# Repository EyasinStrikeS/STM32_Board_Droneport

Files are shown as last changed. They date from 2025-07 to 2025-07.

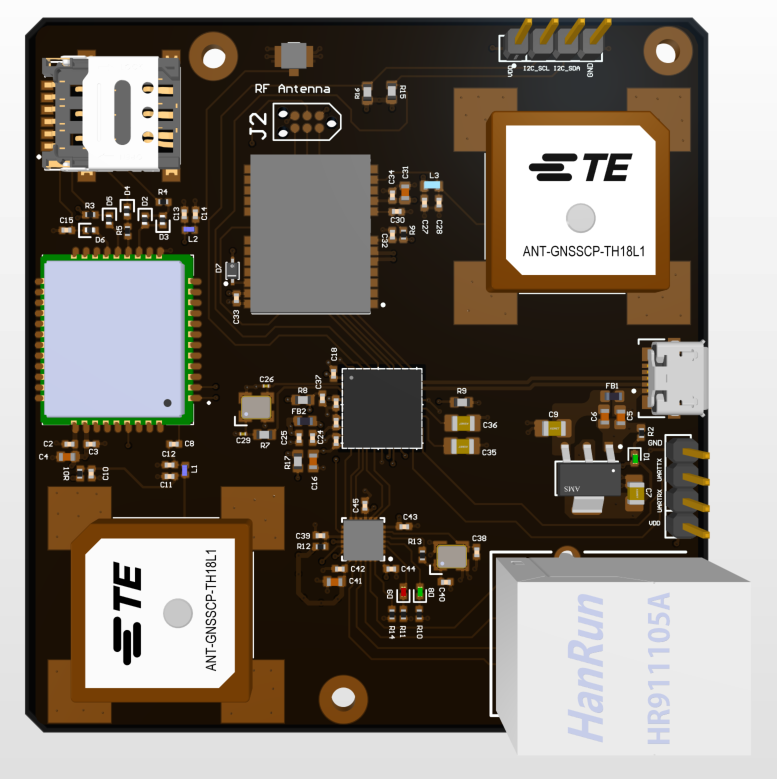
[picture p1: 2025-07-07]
Hardware/PCB/3D PCB View.png

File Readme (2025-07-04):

# Droneport STM32 Hardware Design

## Overview

This project contains the complete schematic and PCB layout for a custom embedded system designed to serve as a **Droneport Communication Controller**. The board integrates multiple interfaces for embedded control and communication:

- STM32H730VBH6 microcontroller
- Ethernet (LAN8720A + RJ45 with magnetics)
- LTE + GNSS module (SIM7080G + NEO-M8N)
- USB, UART, SPI, I2C, SWD, SIM card
- Power regulation (AMS1117-3.3)
- Antenna inputs for GNSS and LTE
- Debug and programming header

---

## Features

- **Core MCU**: STM32H730VBH6 (Cortex-M7, 550 MHz)
- **Communication**:
  - Ethernet via LAN8720A
  - LTE Cat-M/NB-IoT + GNSS via SIM7080G
  - GPS/GNSS via u-blox NEO-M8N
- **Power**: USB 5V input, regulated 3.3V for logic
- **Interfaces**: UARTs, I2C, SPI, SWD debug
- **Antenna**: U.FL for GNSS, LTE RF antenna
- **Connector**: RJ45, USB Micro-B, SIM slot

---

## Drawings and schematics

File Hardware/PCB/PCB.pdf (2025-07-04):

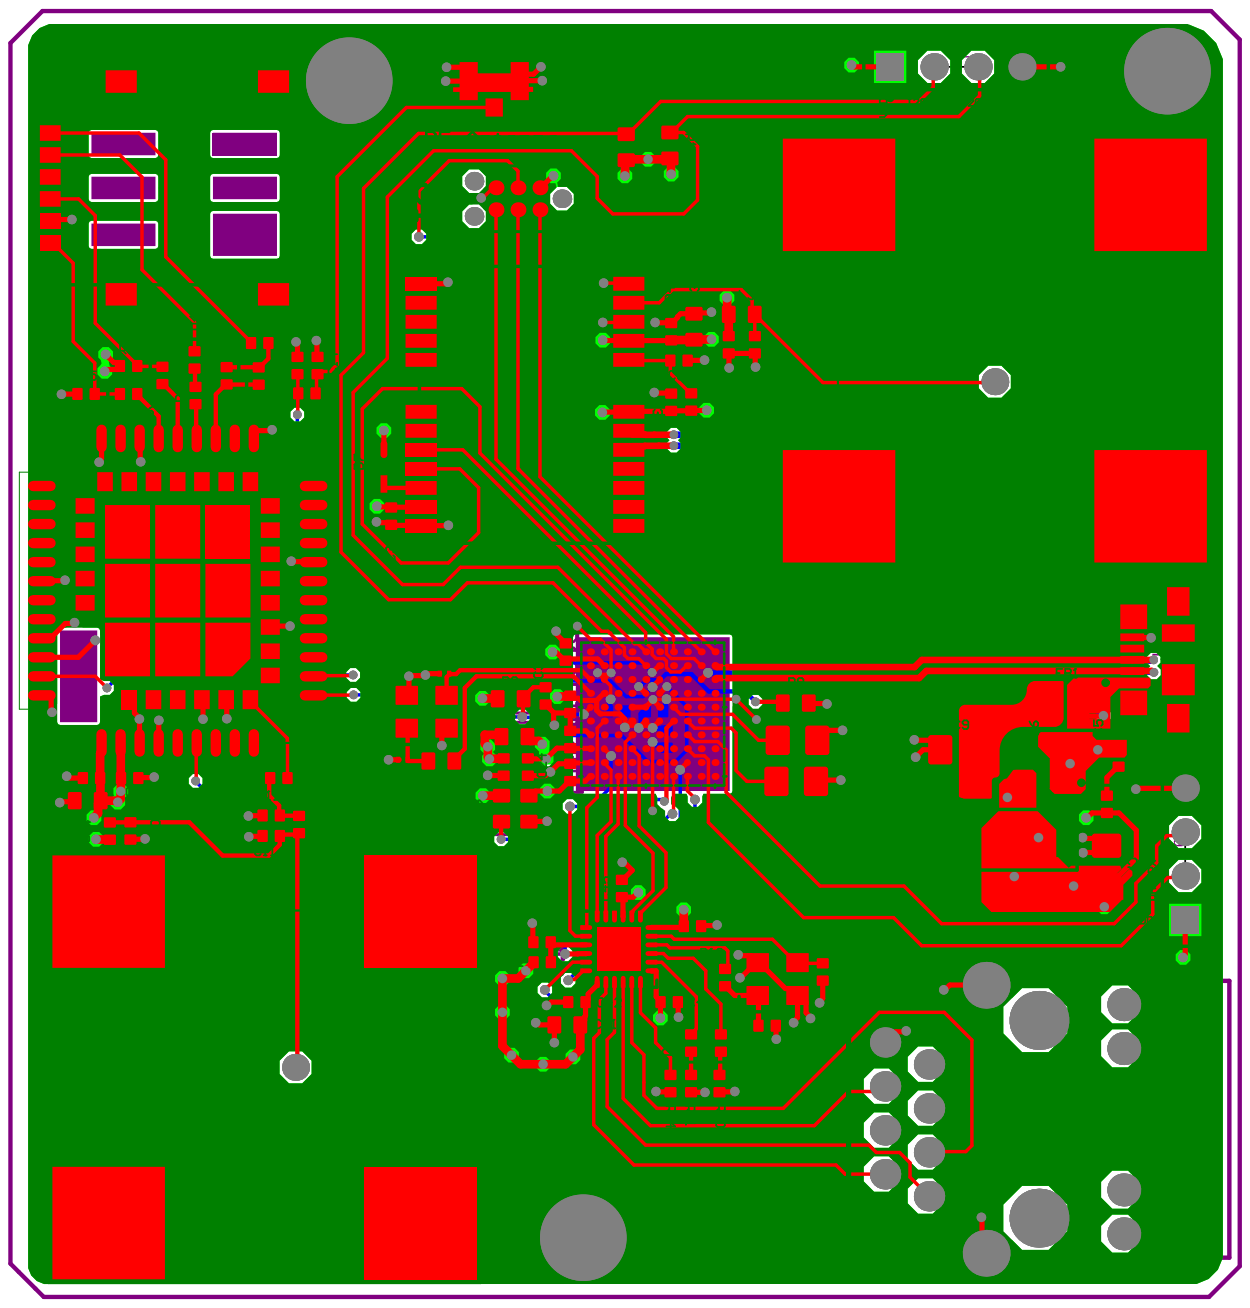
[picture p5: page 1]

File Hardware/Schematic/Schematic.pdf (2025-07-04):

PC15-OSC32_OUT B1 | VBAT B²
PC3_C F3 | VDD F⁴ VDD F⁵ | VDD³USB F⁶

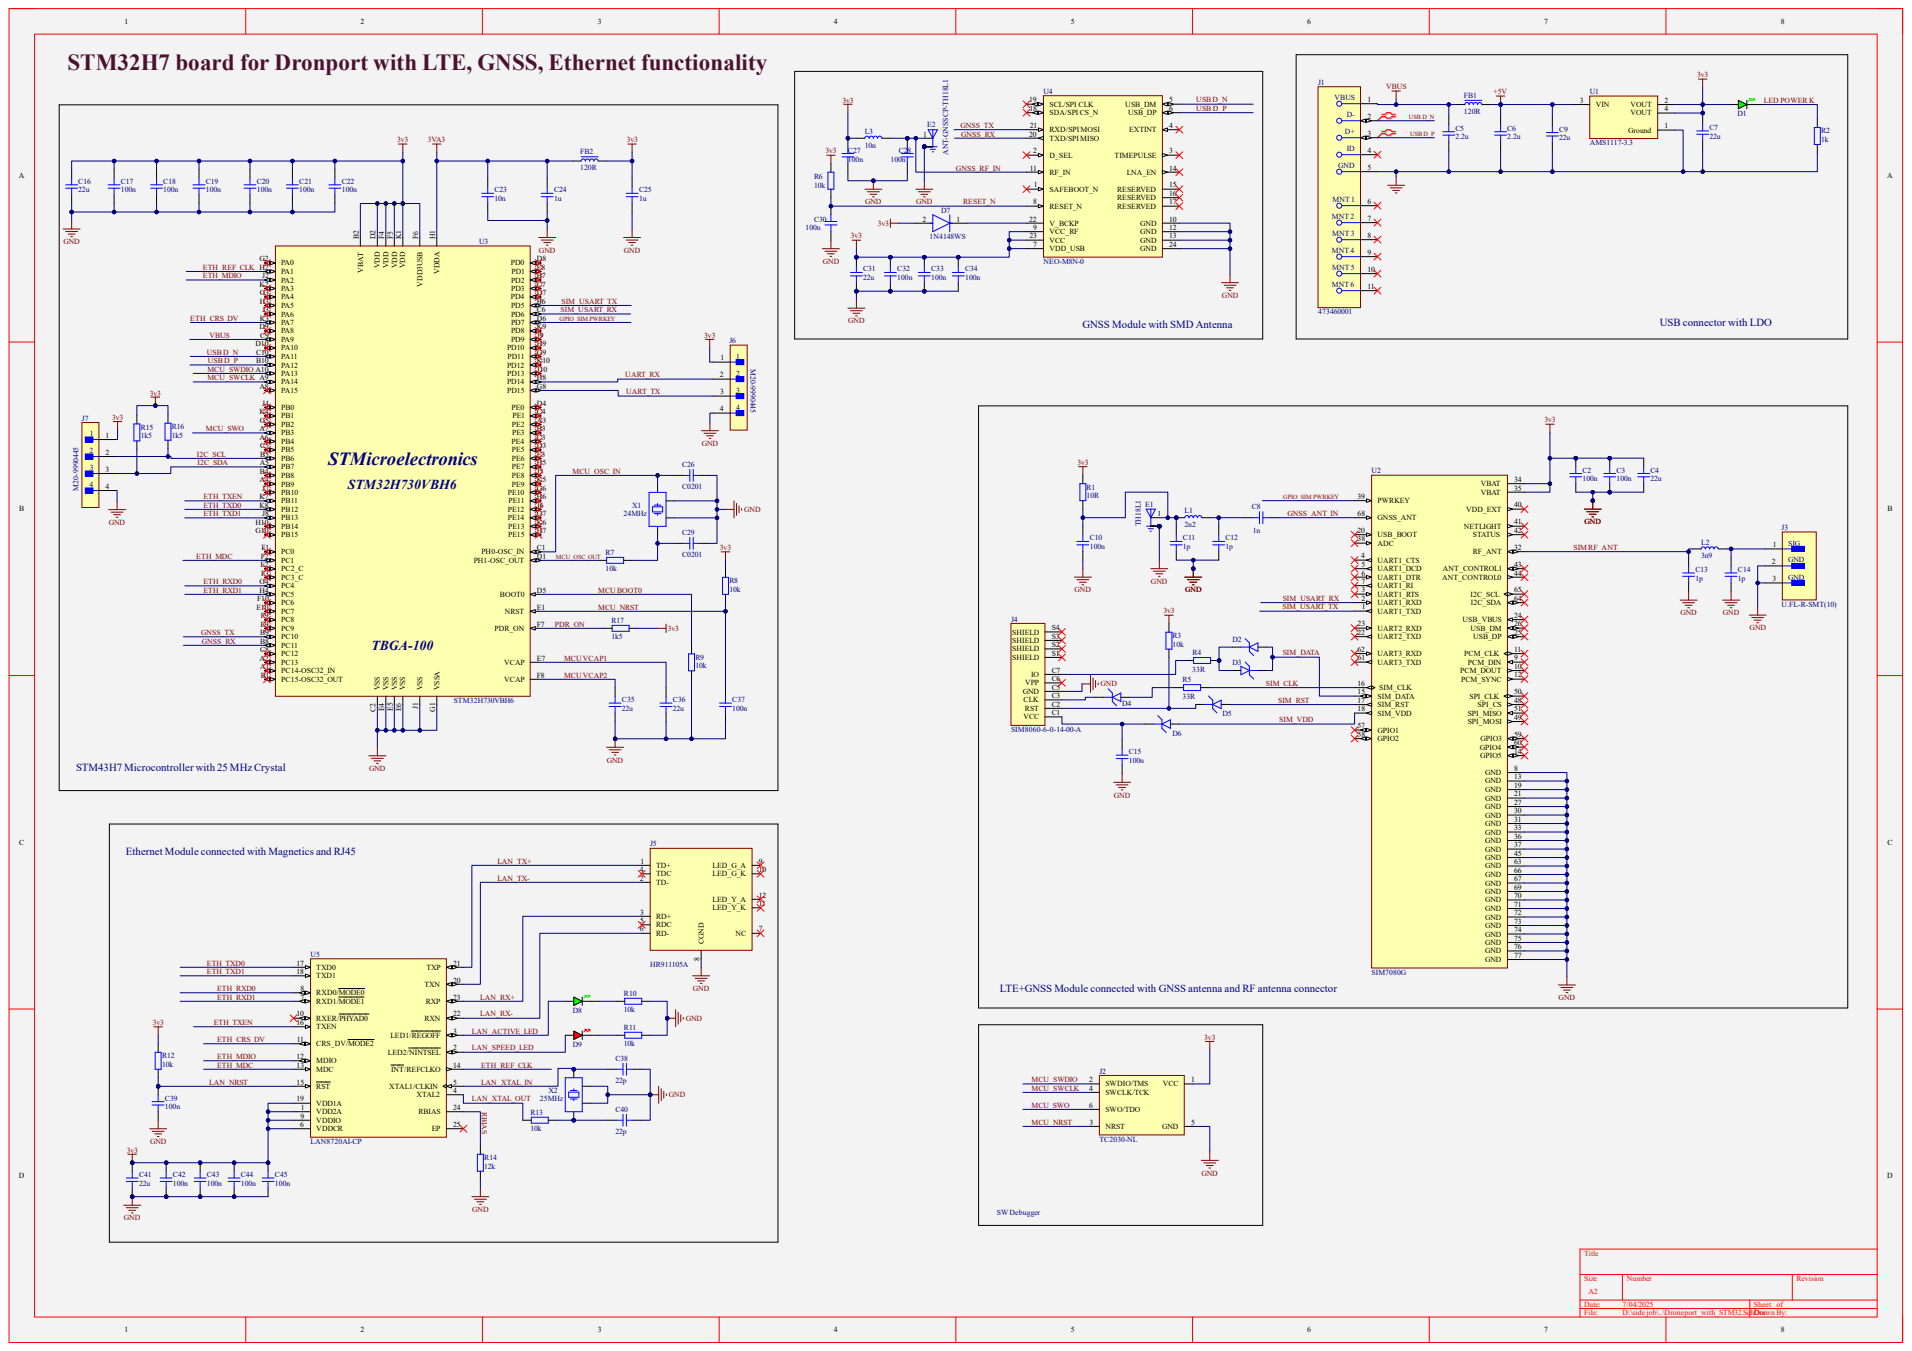
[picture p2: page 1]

STM32H7 board for Dronport with LTE, GNSS, Ethernet functionality

STM43H7 Microcontroller with 25 MHz Crystal

Ethernet Module connected with Magnetics and RJ45

LTE+GNSS Module connected with GNSS antenna and RF antenna connector

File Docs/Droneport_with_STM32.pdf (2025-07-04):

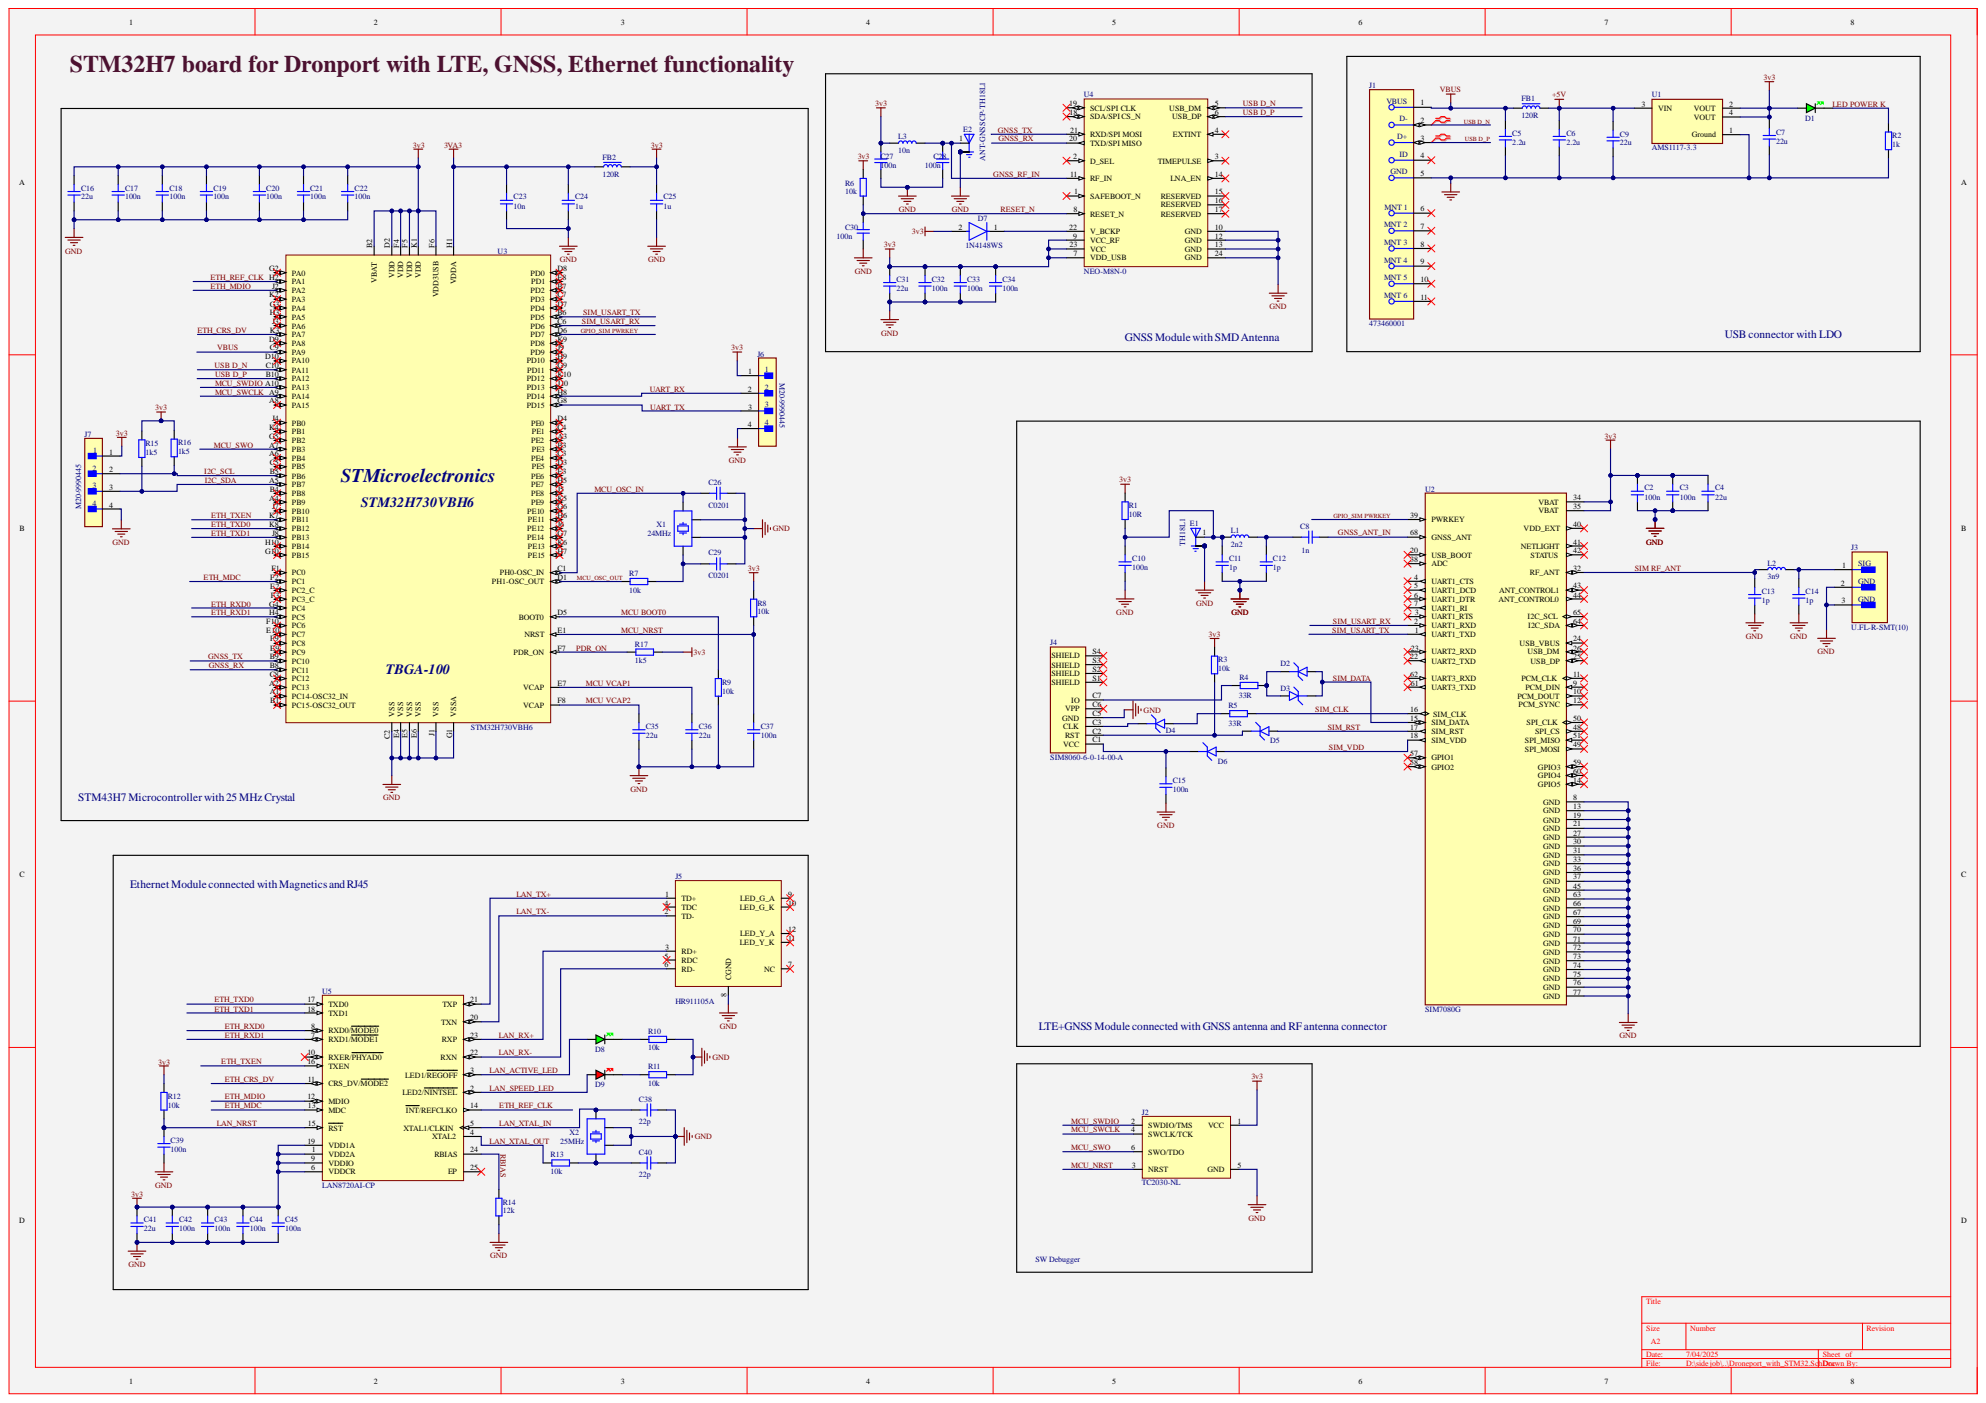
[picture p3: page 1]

STM32H7 board for Dronport with LTE, GNSS, Ethernet functionality

3 | I2C_SDA

I2C_SCL

SIM_VDD | GPIO1 57

STM43H7 Microcontroller with 25 MHz Crystal

Ethernet Module connected with Magnetics and RJ45

LTE+GNSS Module connected with GNSS antenna and RF antenna connector

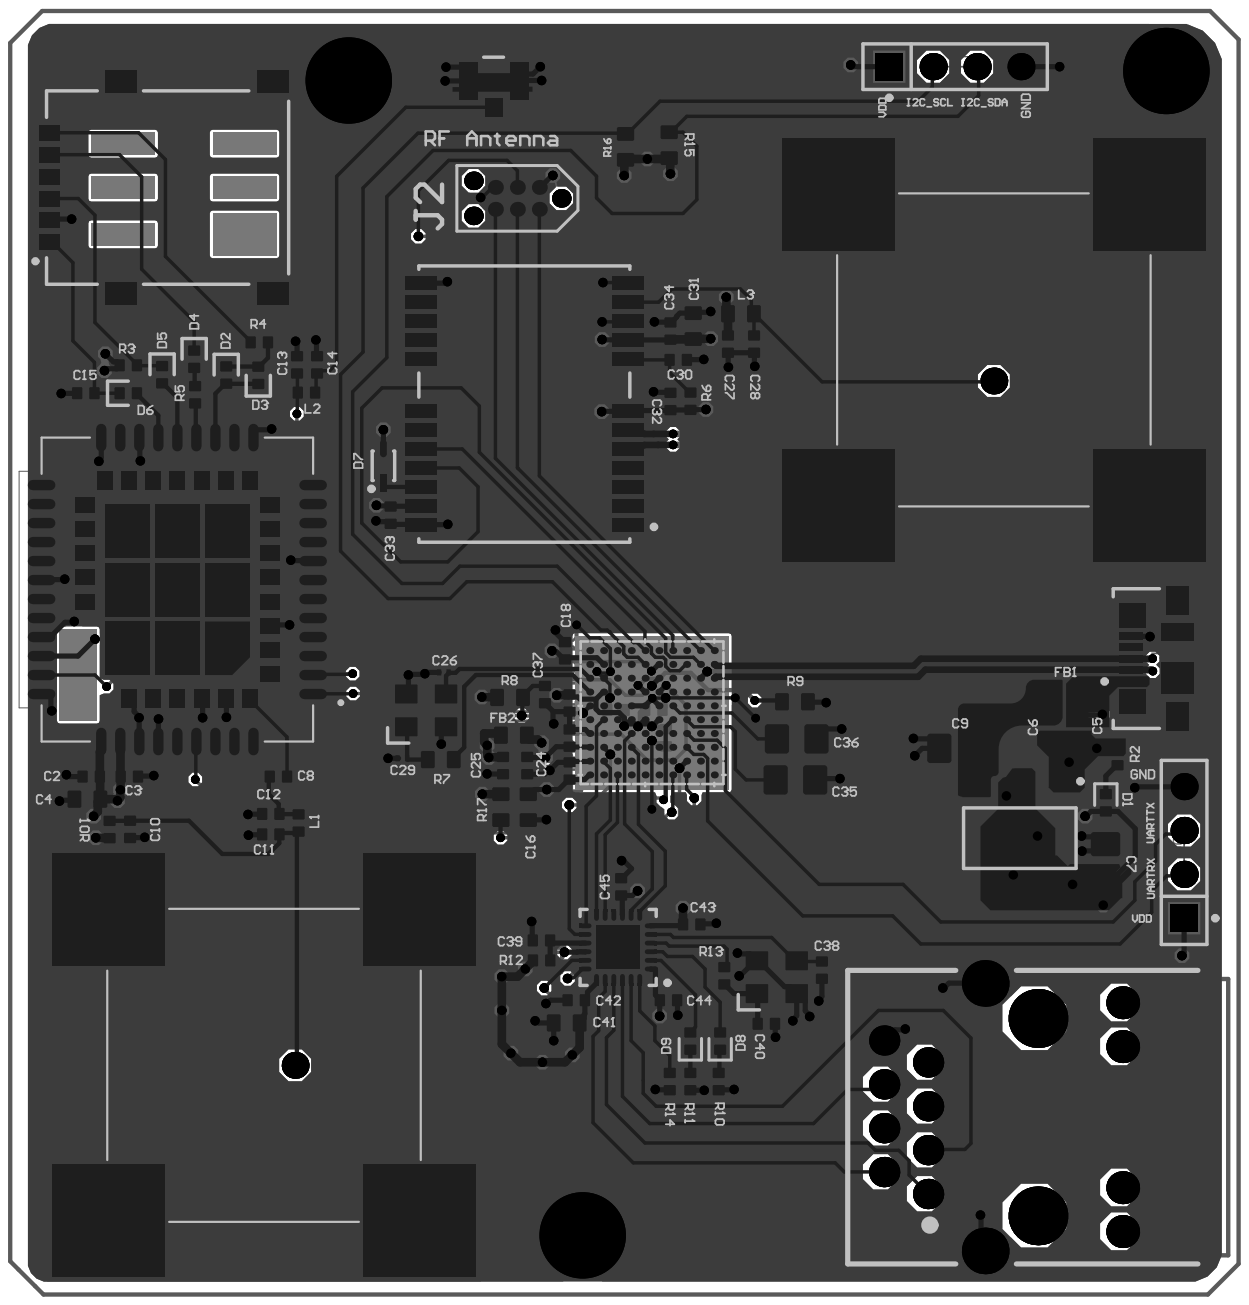
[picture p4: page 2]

Comment | Description | Designator | Footprint | LibRef | Quantity
100n | CapacitorSMD0402 | C2, C3, C10, C15, C17, C18, C19, C20, C21, C22, C27, C28, C30, C32, C33, C34, C37, C39, C42, C43, C44, C45 | CAP_0402 | CAP_0402 | 22
22u | CapacitorSMD0603 | C4, C16, C31, C41 | CAP_0603 | CAP_0603 | 4
2.2u | CapacitorSMD0603 | C5, C6 | CAP_0603 | CAP_0603 | 2
22u | CapacitorSMD0805 | C7, C9, C35, C36 | CAP_0805 | CAP_0805 | 4
1n | CapacitorSMD0402 | C8 | CAP_0402 | CAP_0402 | 1
1p | CapacitorSMD0402 | C11, C12, C13, C14 | CAP_0402 | CAP_0402 | 4
10n | CapacitorSMD0402 | C23 | CAP_0402 | CAP_0402 | 1
1u | CapacitorSMD0402 | C24, C25 | CAP_0402 | CAP_0402 | 2
C0201 | CapacitorSMD0201 | C26, C29 | CAP_0201 | CAP_0201 | 2
22p | CapacitorSMD0402 | C38, C40 | CAP_0402 | CAP_0402 | 2
GREEN | LED0402GREENSMD | D1, D8 | LED_0402_GREEN | LED_0402_GREEN | 2
TVS_DATA | DiodeTVS/ ESD0402 | D2, D3 | D_0402 | D_TVS_0402 | 2
TVS_CLK | DiodeTVS/ ESD0402 | D4 | D_0402 | D_TVS_0402 | 1
TVS_RST | DiodeTVS/ ESD0402 | D5 | D_0402 | D_TVS_0402 | 1
TVS_VDD | DiodeTVS/ ESD0402 | D6 | D_0402 | D_TVS_0402 | 1
1N4148WS | DIODEGENPURP75V 150MASOD323F | D7 | FP-477AB-IPC_C | CMP-07163-000040-1 | 1
RED | LED0402REDSMD | D9 | LED_0402_RED | LED_0402_RED | 1
TH18L1 | | E1 | XCVR_ANT-GNSSCP-TH18L1 | ANT-GNSSCP-TH18L1 | 1
ANT-GNSSCP-TH18L1 | | E2 | XCVR_ANT-GNSSCP-TH18L1 | ANT-GNSSCP-TH18L1 | 1
120R | FerriteBeadSMD0603 | FB1, FB2 | FB_0603 | FB_0603 | 2
473460001 | CONNRCPTUSB2.0 MICROBSMDR/A | J1 | FP-473460001-MFG | CMP-2000-05246-2 | 1
U.FL-R-SMT(10) | CONNU.FLRCPTSTR 50OHMSMD | J3 | FP-U_FL-R-SMT_10-MFG | CMP-0029-00003-2 | 1
SIM8060-6-0-14-00-A | 6PositionCard Connector NANOSIM SurfaceMount, Right AngleGold | J4 | GCT_SIM8060-6-0-14-00-A | SIM8060-6-0-14-00-A | 1
HR911105A | SinglePort RJ45 Connector w/ IntegratedMagnetic andLED10/100Base-T | J5 | HR911105A | HR911105A | 1
M20-9990445 | M20-9990445Conn UnshroudedHeader HDR4POS2.54mm SolderSTThru-Hole Bulk/Loose | J6, J7 | FP-M20-9990445-MFG | CMP-00671-05399696-1 | 2
2n2 | InductorSMD0402 | L1 | IND_0402 | IND_0402 | 1
3n9 | InductorSMD0402 | L2 | IND_0402 | IND_0402 | 1
10n | InductorSMD0603 | L3 | IND_0603 | IND_0603 | 1
10R | ResistorSMD0402 | R1 | RES_0402 | RES_0402 | 1
1k | ResistorSMD0402 | R2 | RES_0402 | RES_0402 | 1
10k | ResistorSMD0402 | R3, R6, R10, R11, R12, R13 | RES_0402 | RES_0402 | 6
33R | ResistorSMD0402 | R4, R5 | RES_0402 | RES_0402 | 2
10k | ResistorSMD0603 | R7, R8, R9 | RES_0603 | RES_0603 | 3
12k | ResistorSMD0402 | R14 | RES_0402 | RES_0402 | 1
1k5 | ResistorSMD0603 | R15, R16, R17 | RES_0603 | RES_0603 | 3
AMS1117-3.3 | LDOVoltage Regulators1A, 3.3V | U1 | FP-AMS1117-IPC_C | CMP-209535-000001-1 | 1
SIM7080G | Cellular, Navigation Galileo, GLONASS, GPS, GNSS, LTE Transceiver Module 1.559GHz~1.576GHz, 1.575GHz~1.576GHz, 1.574GHz~1.606GHz, 1.598GHz~1.563GHz AntennaNot Included SurfaceMount | U2 | XCVR_SIM7080G | SIM7080G | 1
STM32H730VBH6 | 32-bit Arm®Cortex®-M7550MHzMCU, 128 KBFlash, 564KBRAM, 35commsperipherals andanaloginterfaces, TFBGA-100 | U3 | TFBGA100_8X8_STM | STM32H730VBH6 | 1
NEO-M8N-0 | U-BloxM8Concurrent GnssModule, 3.6V, -40to85degC, 24-Pin SMD, RoHS, Tapeand Reel | U4 | UBX-NEO-M8-24_V | CMP-2000-07559-1 | 1
LAN8720AI-CP | RMII10/100Ethernet Transceiver withHP Auto-MDIXSupport, -40to85degC, 24-Pin QFN, RoHS, Tray | U5 | MCHP-QFN-24_V | CMP-2000-05216-1 | 1
24MHz | Crystal SMD24MHz 10PPM7pF3225 | X1 | XTAL_3225 | TSX-3225_24.0000MF15X-AC | 1
25MHz | Crystal SMD24MHz 10PPM7pF3225 | X2 | XTAL_3225 | TSX-3225_24.0000MF15X-AC | 1
